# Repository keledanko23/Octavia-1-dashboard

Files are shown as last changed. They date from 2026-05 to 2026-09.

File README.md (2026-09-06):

# Octavia-1-Dashboard

A dashboard project.

## 📋 Project Overview

This is the Octavia-1 Dashboard - a comprehensive dashboard solution designed to use for pc simulators.
I have significantly expanded the scope of this project into a multi-phase hardware and software engineering build. I am converting a physical Skoda Octavia MK1 instrument cluster into a high-fidelity, real-time PC flight/racing simulator telemetry display.

## Current Progress (73 Hours Logged):

Hardware Reverse Engineering: Analyzed the internal trace lines, power rail limits, and motor pinouts of a replacement cluster following a previous hardware       failure (which was an excellent learning experience).
Interface Board Fabrication: Built a fully functional hardware interface on a 5x7cm barna perfboard, permanently soldering 3 driver ICs to safely handle logic     signal conversions between the microcontroller and the dashboard.
Complex Wire Harnessing: Engineered a point-to-point jumper wire harness to break out the connections. Applied hot-melt adhesive to insulate exposed solder        joints and provide mechanical strain relief.
Finished PCB design

## Remaining Scope:

Firmware Development: Writing custom python code using tkinter to simulate how it should work
Custom PCB Shield Design: Try to create a pcb for it.

## Diary

### 1st log (3.5 hours)
Analyzed the internal board layout of the replacement cluster. Traced the circuit lines to find the correct entry points for the stepper motors and indicators to avoid another hardware failure.
  ### Disassembly
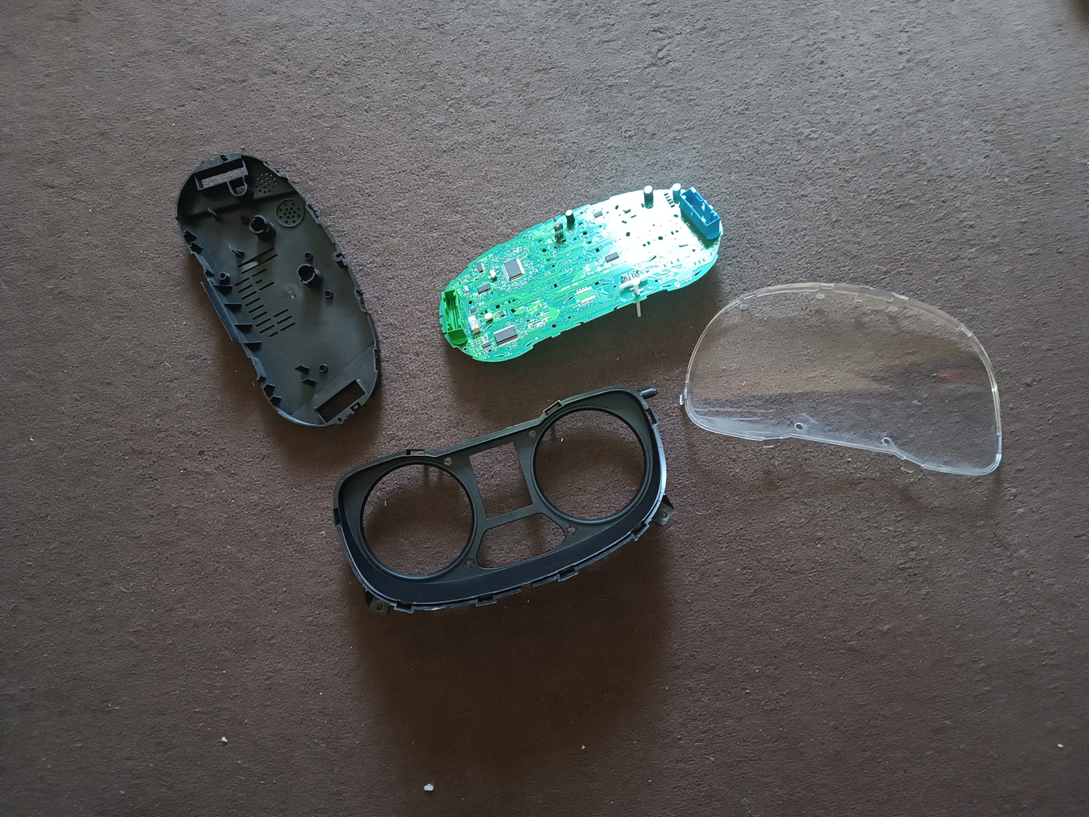
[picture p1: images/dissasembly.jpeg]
Disassembly
  

  ### LEDS
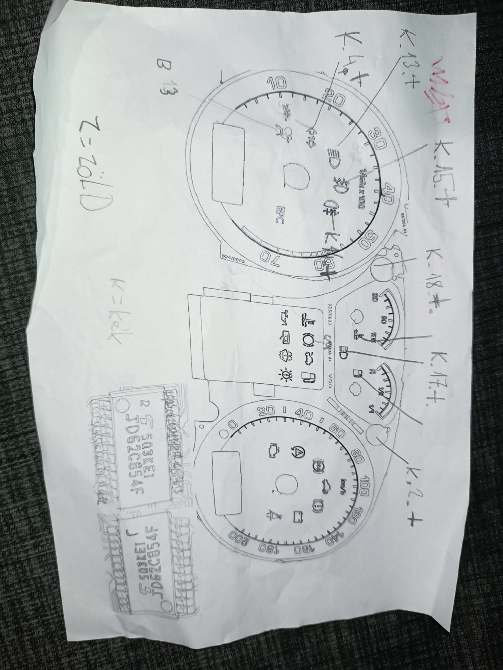
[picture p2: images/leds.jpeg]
LEDS
  

  ### Pinout
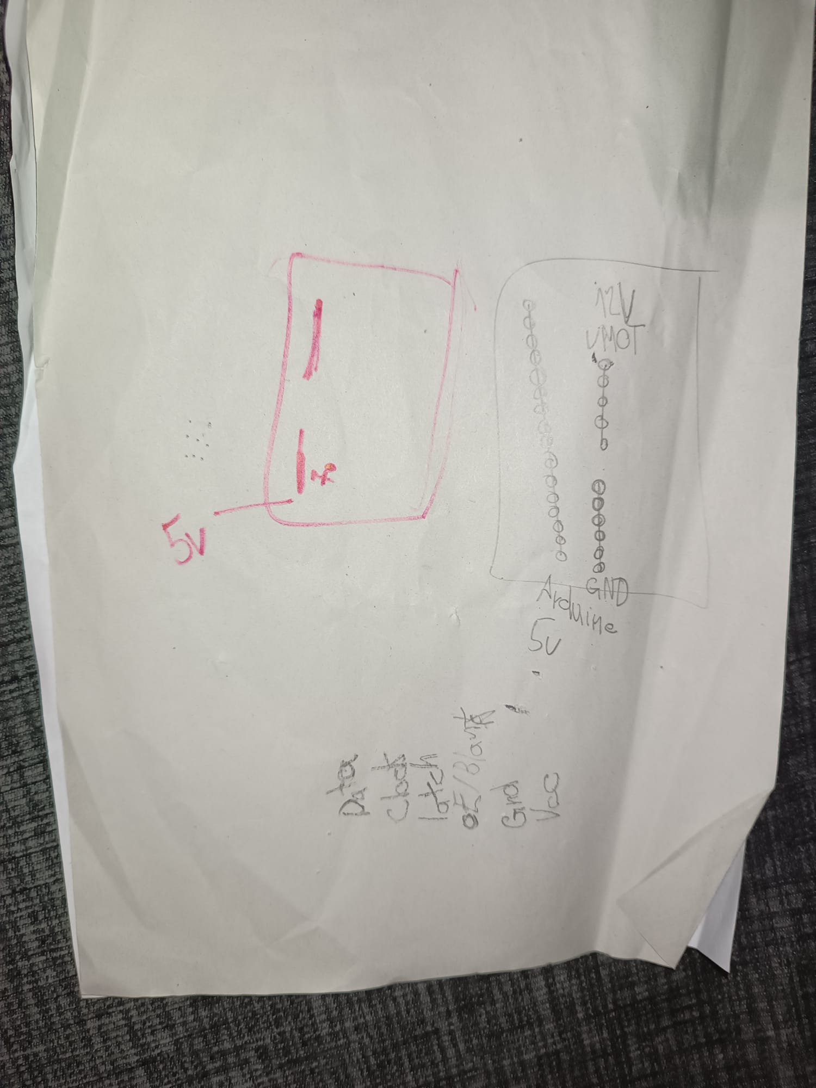
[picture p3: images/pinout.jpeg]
Pinout


## 2nd log (4 hours)
Mapped out the component placement on the 5x7cm barna perfboard. Positioned the three driver ICs and the male headers, then permanently soldered them onto the prototype board.

  ### ICs
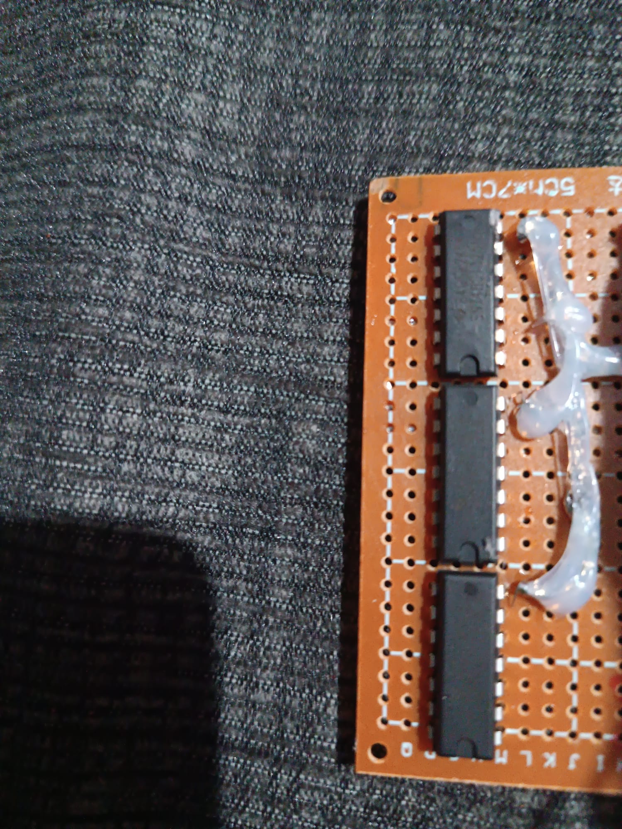
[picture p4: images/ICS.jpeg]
ICs
  

## 3rd log (4.5 hours)
Started building the complex point-to-point jumper wire harness. Stripped, routed, and soldered individual wires from the IC legs to the breakout headers to safely transfer signals.

  ### Wires
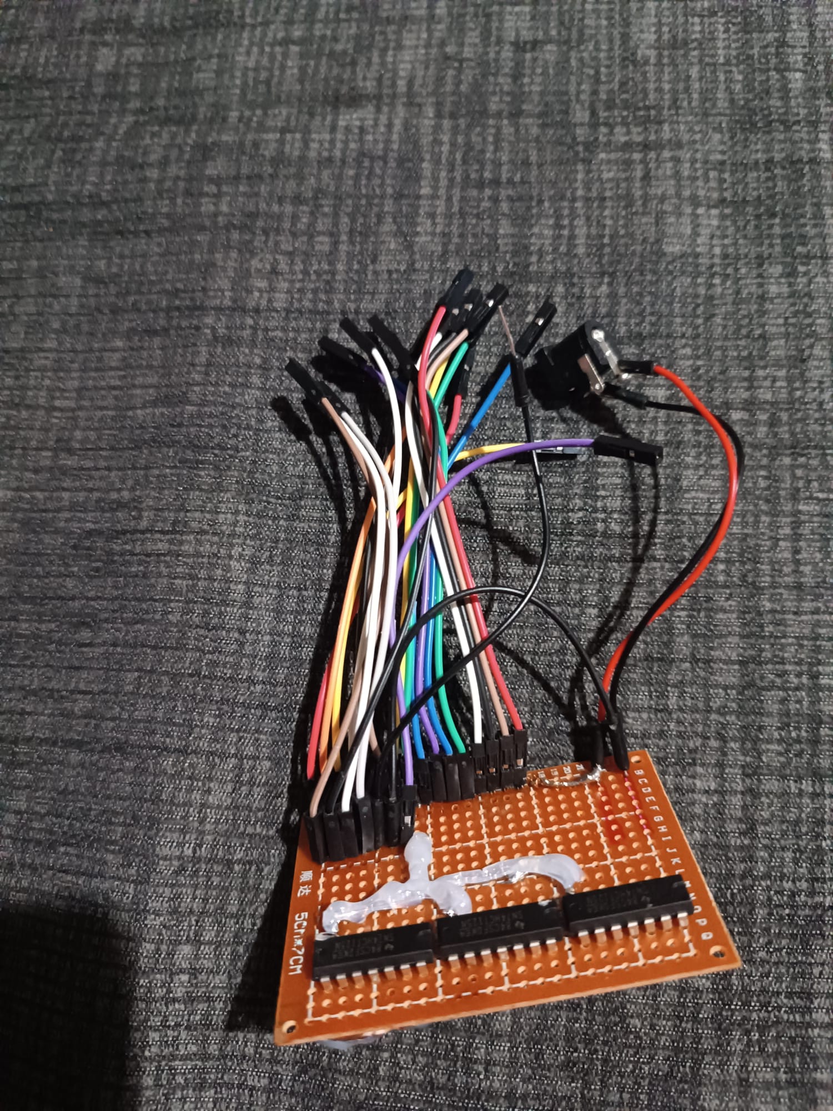
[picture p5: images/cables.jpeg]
Wires
  

## 4th log (4 hours)
Used a multimeter to test continuity on every single soldered connection. Checked for accidental solder bridges between the IC pins to prevent any short circuits before testing on live power.
 
  ### Checking
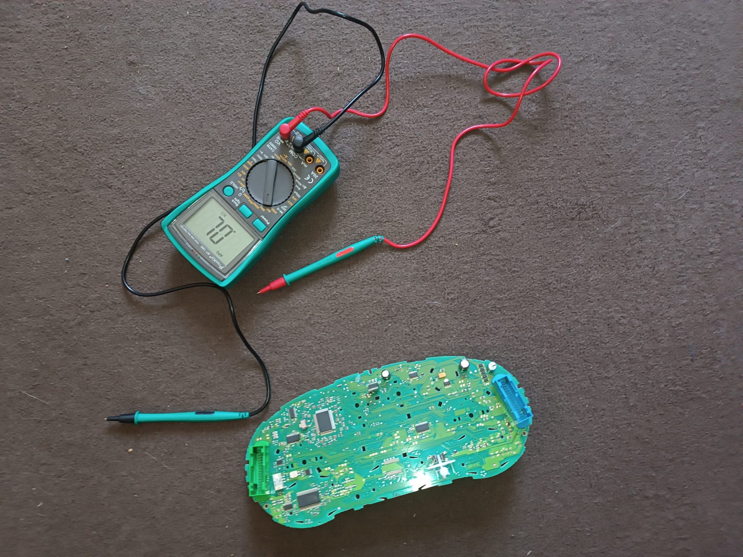
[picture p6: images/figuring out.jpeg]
Checking
  

## 5th log (4 hours)
Completed the hardware prototyping phase. Applied layers of hot-melt adhesive over the wire cluster to insulate the exposed solder joints and provide mechanical strain relief against loose connections.

  ### Coating
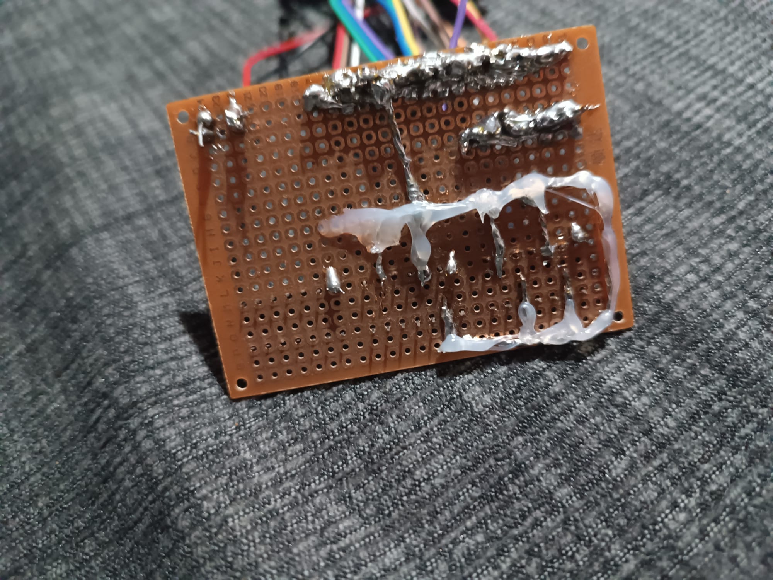
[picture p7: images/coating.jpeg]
Coating
  

## 6th log (5 hours)
Completed a simulation python code that shows how it will work.

  ### Python screenshot
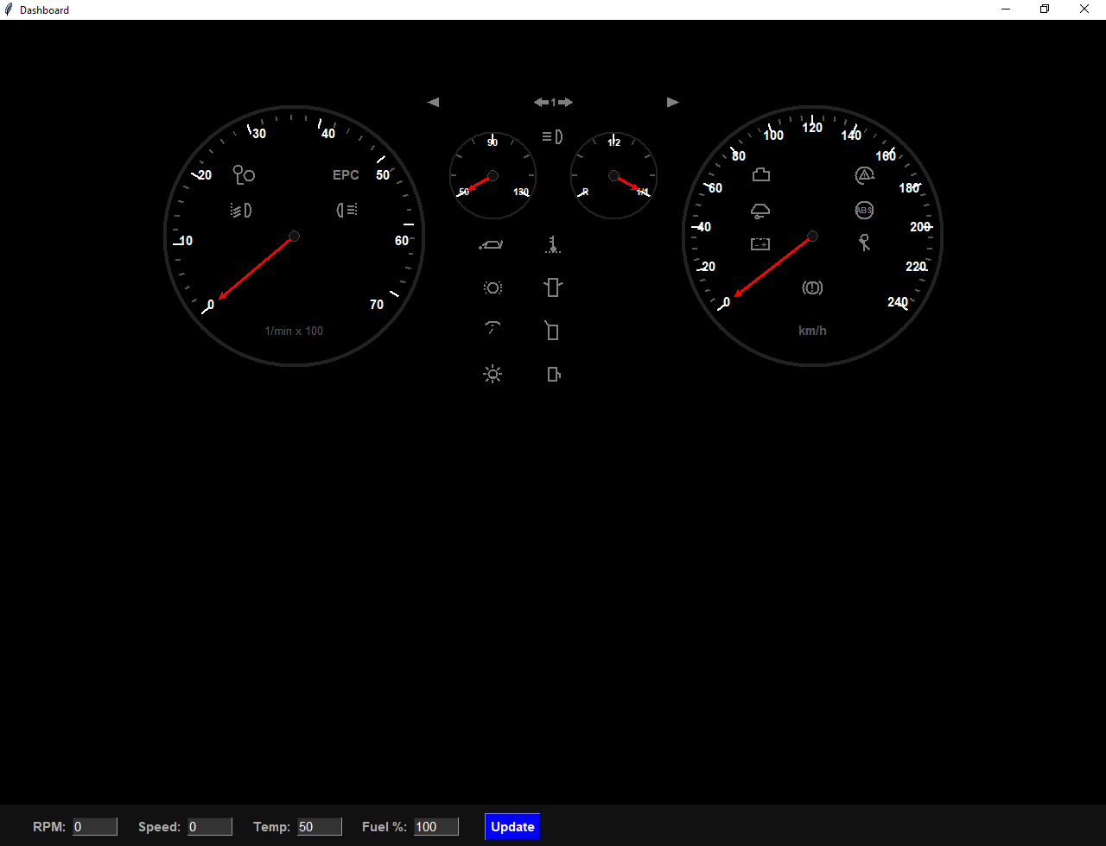
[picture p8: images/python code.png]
Python code
  

  ## DEMO LINK: https://youtu.be/50QhlQHXBYw

  ## PYTHON CODE [HERE](https://github.com/keledanko23/Octavia-1-dashboard/blob/main/Octavia%20mk1%20dashboard%20python%20code.py)
  
  ## 7th log(2.5 hours)
  Started mapping out the pcb so i can recreate it later, added 1more led to the prototype, tried to add 2more but they burned out
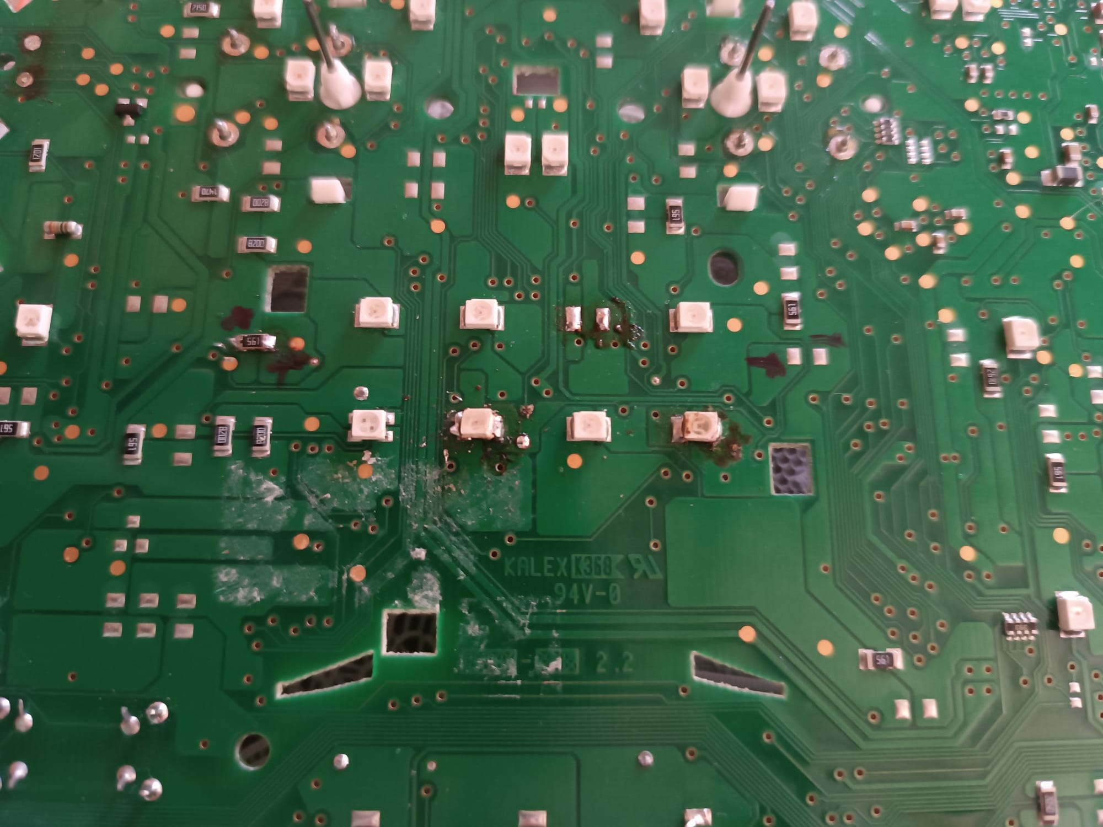
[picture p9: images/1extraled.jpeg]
LED
  
  
  ## 8th log(9.2 hours)
  Started building the pcb outlines and holes, unfortunatly lot of the holes arent on their places where they should be even if i mesure 10 times, at least the outline is finally the form i need and some of the holes ar on their places.
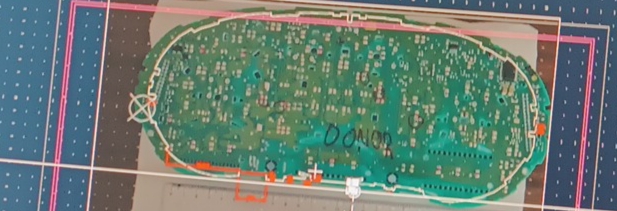
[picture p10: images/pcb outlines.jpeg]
Outlines
   
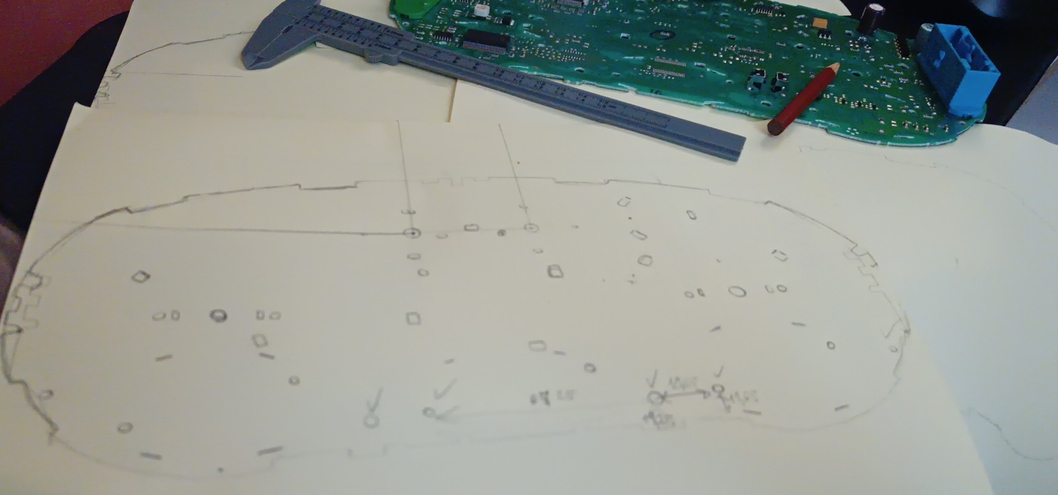
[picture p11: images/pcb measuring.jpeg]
Measuring
    

## 9th log(3.7 hours)
Finaly got a chance to use a scaner to scan the pcb, imported it into kicad ad fixed al the kholes location and the form of the pcb, the pcb form is now finished
  
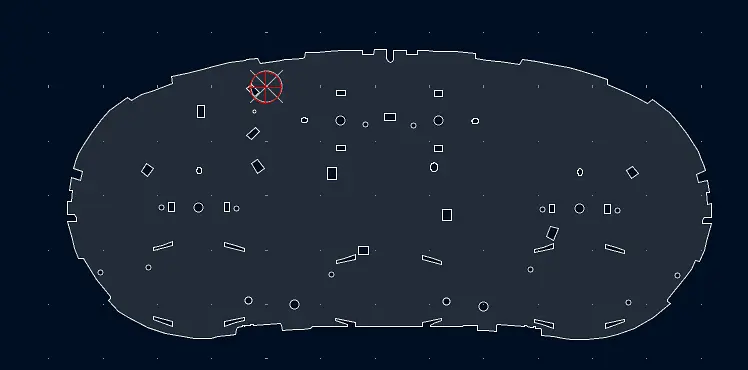
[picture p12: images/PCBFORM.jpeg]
PCB form
  

## 10th log(7 hours)
Drawed the schematic, it was really hard because I did not find some IC-s and had to draw them myself, at first it had 56errors but i managed to fix it

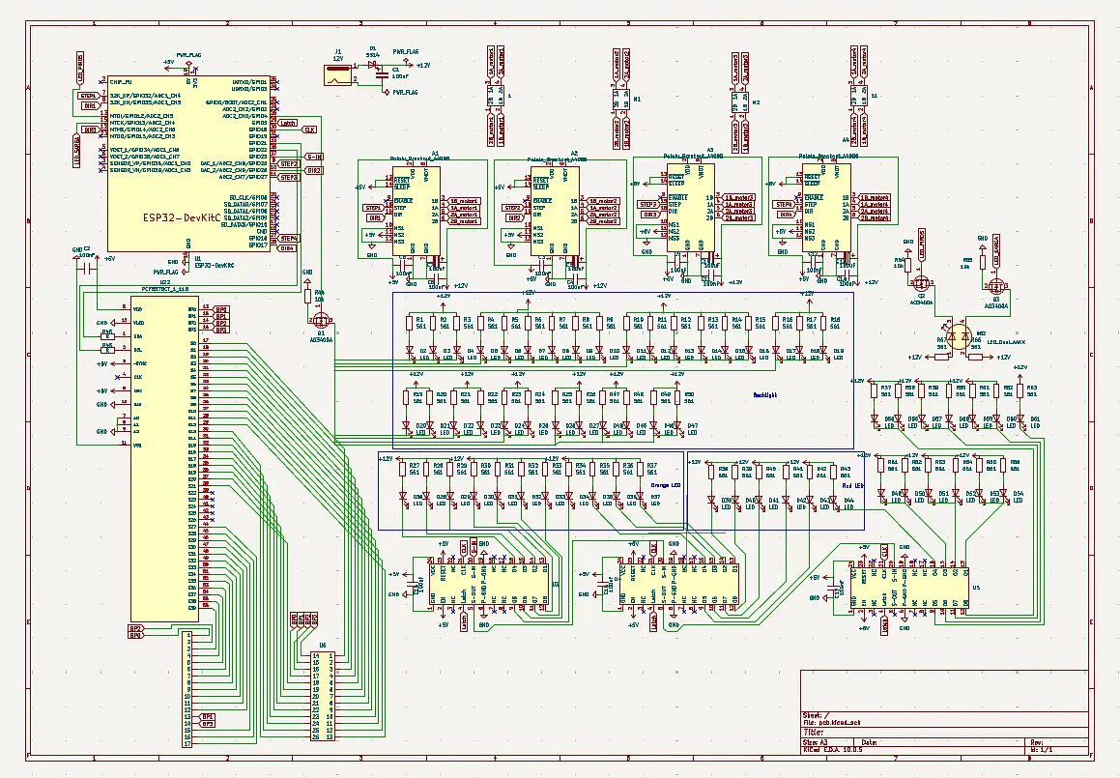
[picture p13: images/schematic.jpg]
Schematic


## 11th log(9 hours)
Added the components and conected most of the traces but I can´t make it cleaner, and i ran the DRC it said it has 250 errors and 110 alerts so i have a lot of work to do.

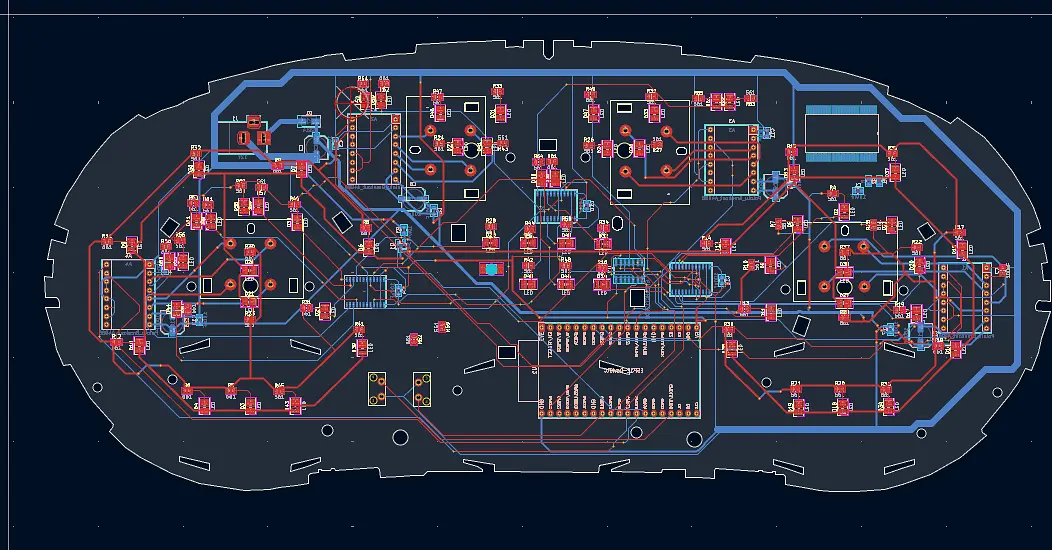
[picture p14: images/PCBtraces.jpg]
PCB traces


## 12th log(9.2 hours)
Fixed the layout, changed some expensive IC-s to cheaper ones, almost finished

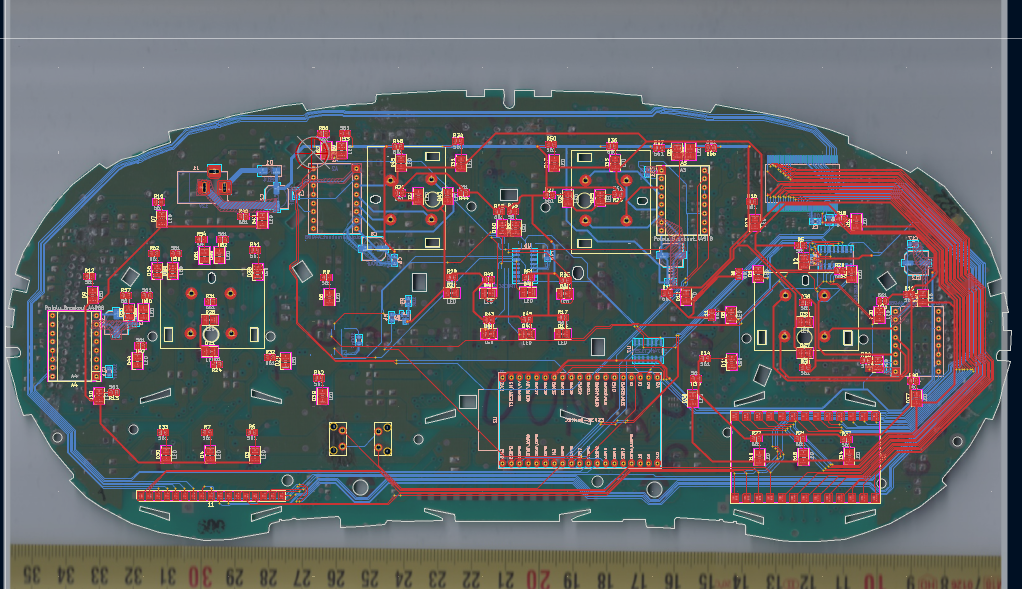
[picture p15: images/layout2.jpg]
Layout


## 13th log(5.8 hours)
Finally finished the pcb, it´s ready for order

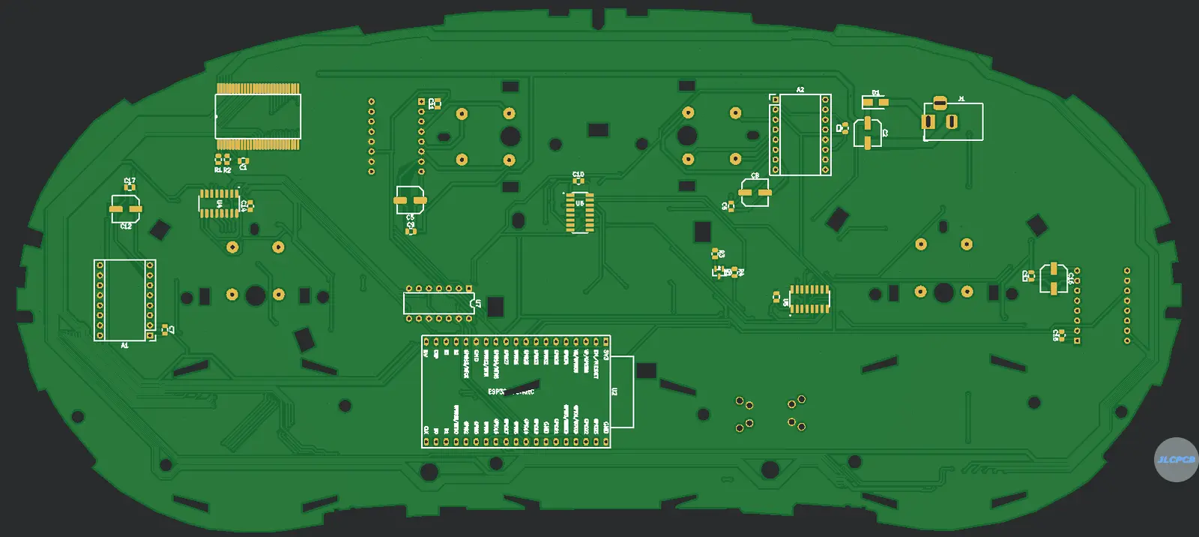
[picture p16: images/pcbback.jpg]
PCB back

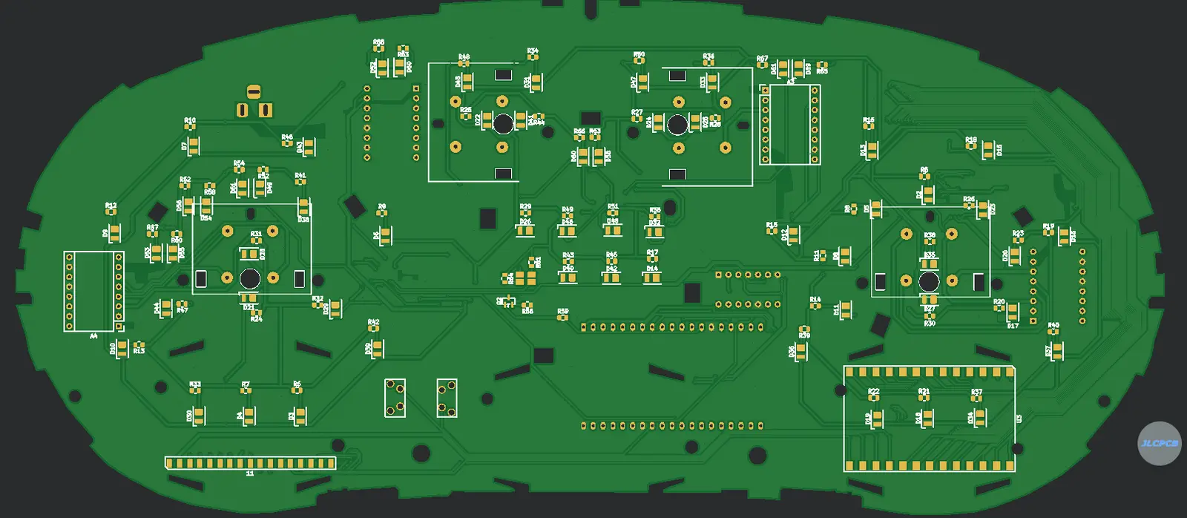
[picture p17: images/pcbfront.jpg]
PCB front


## PCB FILES [HERE](https://github.com/keledanko23/Octavia-1-dashboard/tree/main/PCB%20FILES)

## [BOM IN TABLE FOMRAT](https://docs.google.com/spreadsheets/d/1glcknnUEBRp5D3enFJscNNNqzlTzyaNK3k0CQGIx504/edit?usp=sharing)

**Last Updated:** August 29, 2026

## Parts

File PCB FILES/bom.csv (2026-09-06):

Designator | Footprint | Quantity | Value | LCSC Part #
11 | LCDPADS_LEFT1 | 1 | ~
21, 31, M1, M2 | Bez názvu | 4 | ~
A1, A2, A3, A4 | Pololu_Breakout-16_15.2x20.3mm | 4 | Pololu_Breakout_A4988
C1, C10, C11, C13, C14, C15, C17, C3, C4, C6, C7, C9 | 0805 | 12 | 100nF
C12, C16, C2, C5, C8 | C_Elec_6.3x7.7 | 5 | 100uF
D1 | D_DO-15_P10.16mm_Horizontal | 1 | SS14
D10, D11, D12, D13, D14, D15, D16, D17, D18, D19, D2, D20, D21, D22, D23, D24, D25, D26, D27, D28, D29, D3, D30, D31, D32, D33, D34, D35, D36, D37, D38, D39, D4, D40, D41, D42, D43, D44, D45, D46, D47, D48, D49, D5, D50, D51, D52, D53, D54, D55, D56, D58, D59, D6, D60, D61, D62, D63, D7, D8, D9 | LED_PLCC_2835_Handsoldering | 61 | LED
J1 | BarrelJack_Horizontal | 1 | 12V
Q1, Q2 | SOT-23_Handsoldering | 2 | AO3400A
R1, R2 | 0805 | 2 | 4,7k
R10, R11, R12, R13, R14, R15, R16, R17, R18, R19, R20, R21, R22, R23, R24, R25, R26, R27, R28, R29, R30, R31, R32, R33, R34, R35, R36, R37, R38, R39, R40, R41, R42, R43, R44, R45, R46, R47, R48, R49, R5, R50, R51, R52, R53, R54, R55, R57, R58, R6, R60, R62, R63, R64, R65, R66, R67, R68, R7, R8, R9 | 0805 | 61 | 561
R3, R56 | 0805 | 2 | 10k
R4, R59 | 0805 | 2 | 331
SW1, SW2 | Bez názvu | 2 | SW_Push
U1 | PCFCHIP | 1 | PCF8576CT_1_118 | PCF8576CT/1,118
U2 | ESP32-DevKitC | 1 | ESP32-DevKitC
U3 | LCDPADS_RIGHT1 | 1 | ~
U4, U5, U6 | SOIC127P600X175-16N | 3 | TPIC6C595DG4
U7 | DIP-14_W7.62mm | 1 | SN74HCT125DR

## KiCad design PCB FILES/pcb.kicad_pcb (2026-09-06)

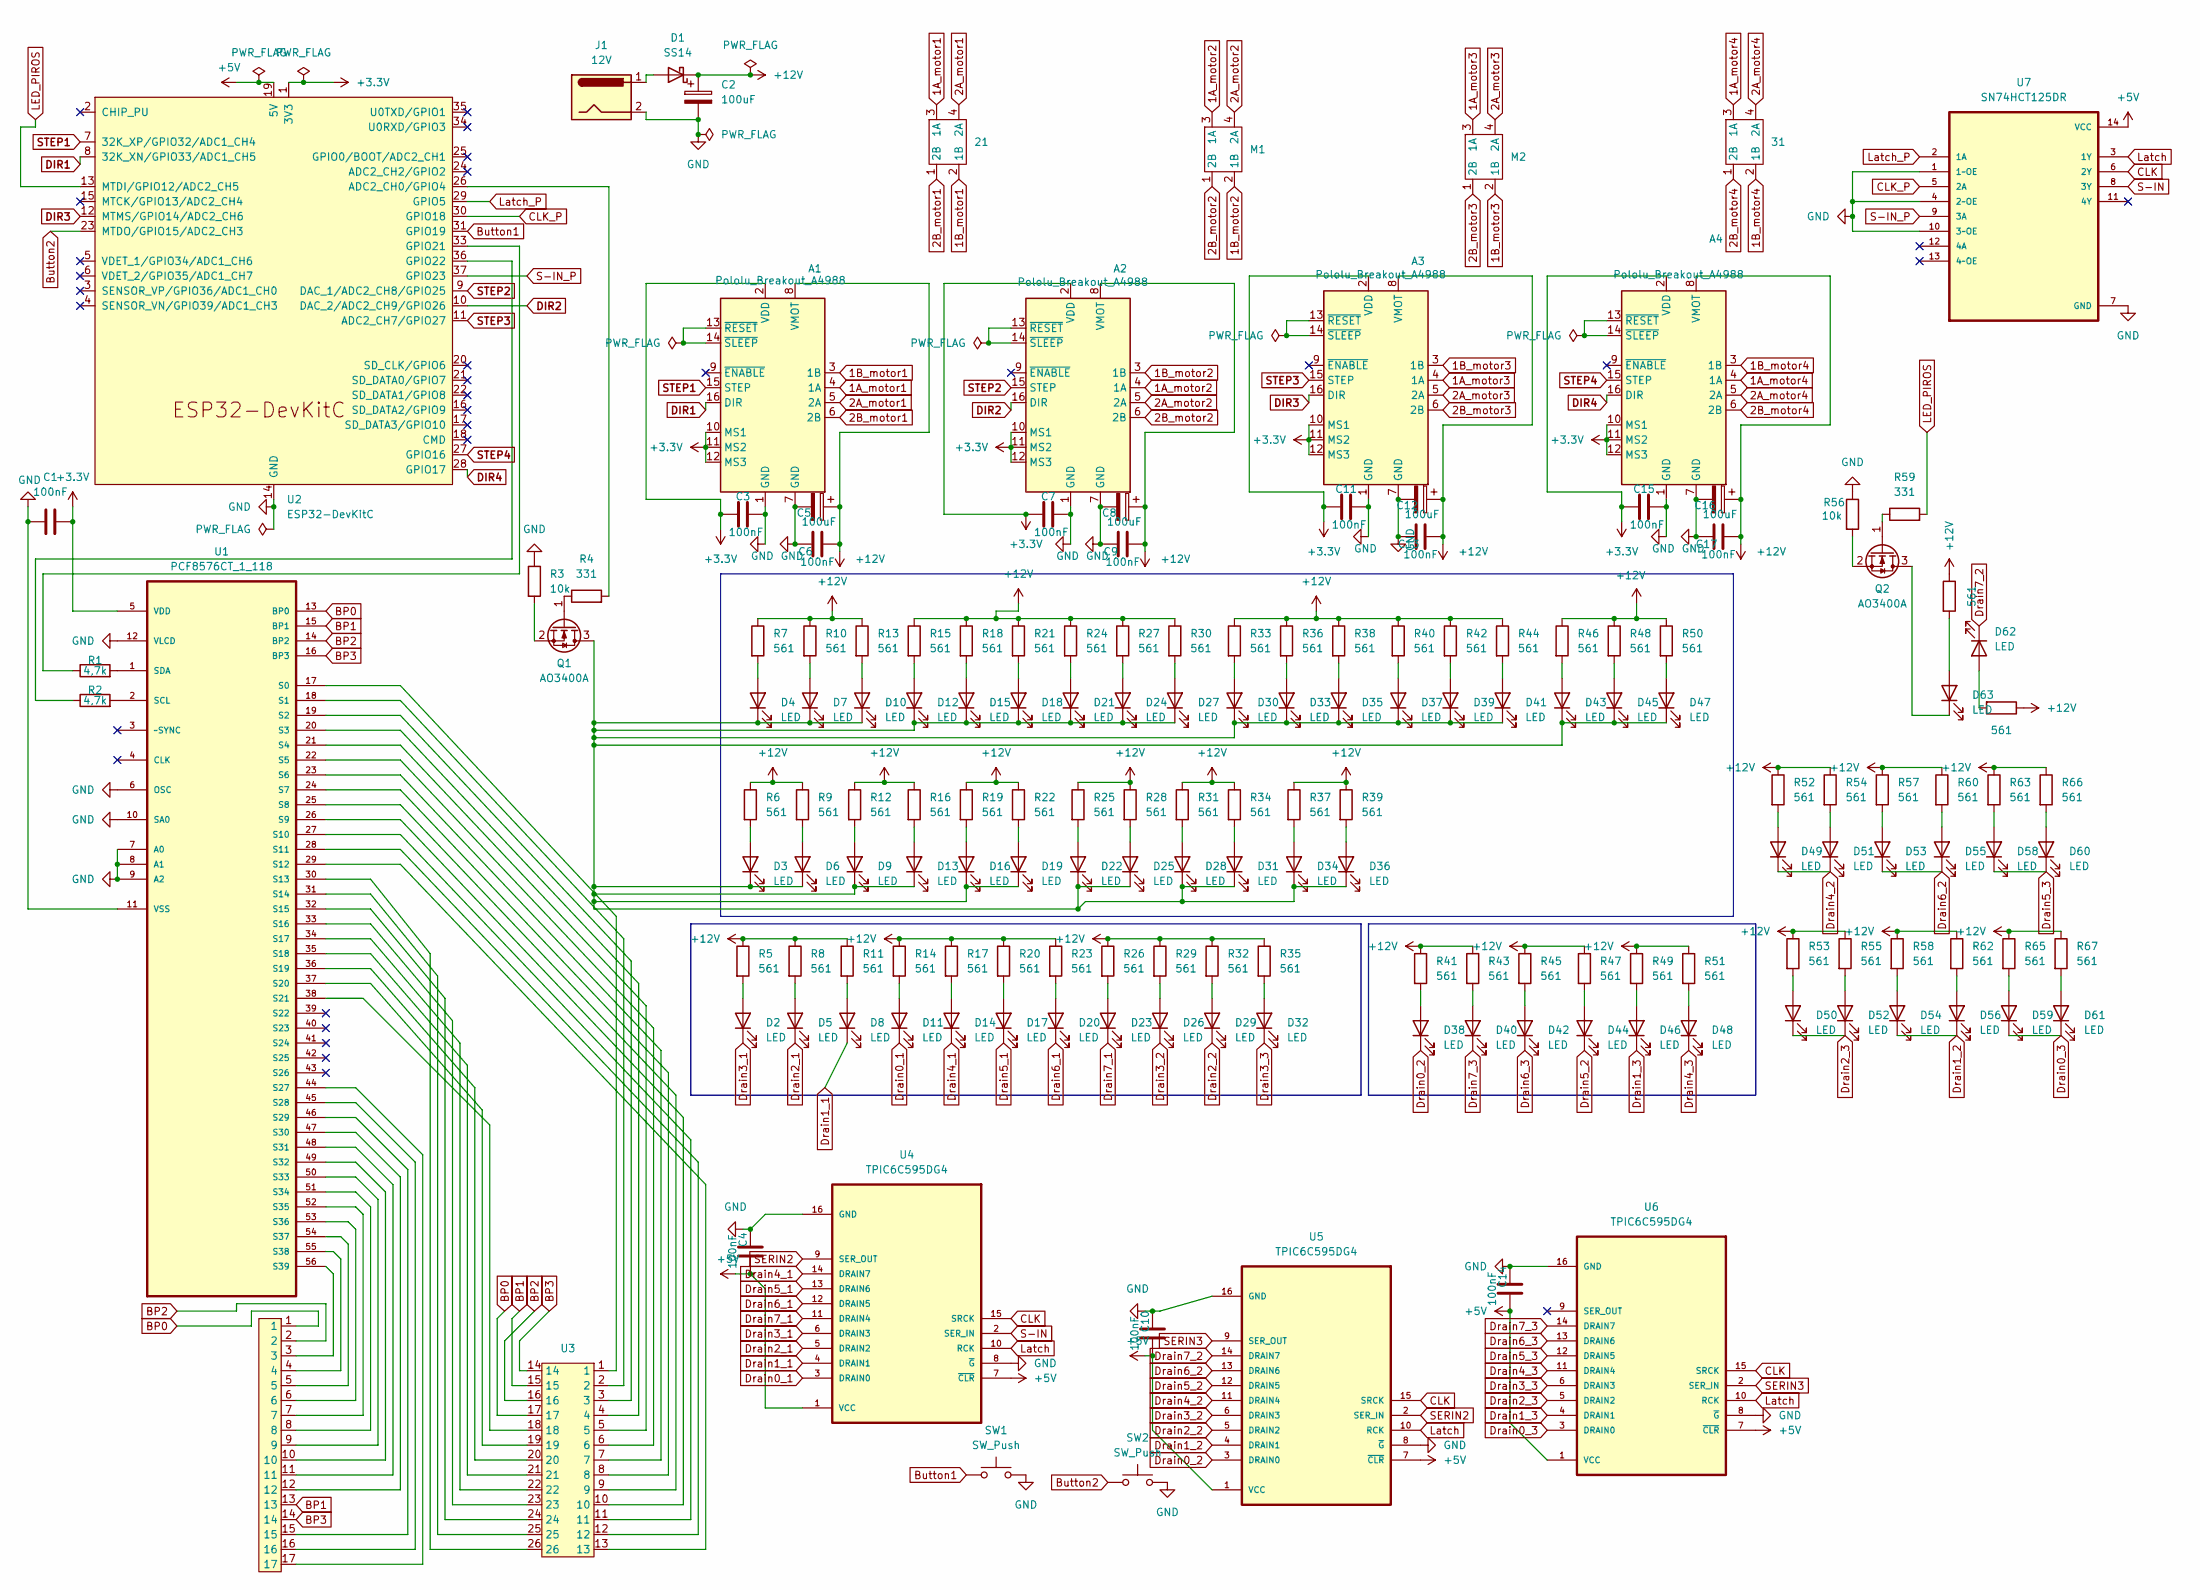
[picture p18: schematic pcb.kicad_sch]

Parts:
11: LCDPADS_LEFT1
21, 31: Bez názvu
A1, A2, A3, A4: Pololu_Breakout_A4988; Pololu_Breakout-16_15.2x20.3mm
C1, C3, C4, C6, C7, C9, C10, C11, C13, C14, C15, C17: 100nF; C_0805_2012Metric_Pad1.18x1.45mm_HandSolder
C2, C5, C8, C12, C16: 100uF; C_Elec_6.3x7.7
D1: SS14; D_DO-15_P10.16mm_Horizontal
D2, D3, D4, D5, D6, D7, D8, D9, D10, D11, D12, D13, D14, D15, D16, D17, D18, D19, D20, D21, D22, D23, D24, D25, D26, D27, D28, D29, D30, D31, D32, D33, D34, D35, D36, D37, D38, D39, D40, D41, D42, D43, D44, D45, D46, D47, D48, D49, D50, D51, D52, D53, D54, D55, D56, D58, D59, D60, D61, D62, D63: LED; LED_PLCC_2835_Handsoldering
J1: 12V; BarrelJack_Horizontal
M1, M2: Bez názvu
Q1, Q2: AO3400A; SOT-23_Handsoldering
R1, R2: 4,7k; R_0805_2012Metric_Pad1.20x1.40mm_HandSolder
R3, R56: 10k; R_0805_2012Metric_Pad1.20x1.40mm_HandSolder
R4, R59: 331; R_0805_2012Metric_Pad1.20x1.40mm_HandSolder
R5, R6, R7, R8, R9, R10, R11, R12, R13, R14, R15, R16, R17, R18, R19, R20, R21, R22, R23, R24, R25, R26, R27, R28, R29, R30, R31, R32, R33, R34, R35, R36, R37, R38, R39, R40, R41, R42, R43, R44, R45, R46, R47, R48, R49, R50, R51, R52, R53, R54, R55, R57, R58, R60, R62, R63, R64, R65, R66, R67, R68: 561; R_0805_2012Metric_Pad1.20x1.40mm_HandSolder
SW1, SW2: SW_Push; Bez názvu
U1: PCF8576CT_1_118; PCFCHIP; MPN PCF8576CT/1,118
U2: ESP32-DevKitC
U3: LCDPADS_RIGHT1
U4, U5, U6: TPIC6C595DG4; SOIC127P600X175-16N
U7: SN74HCT125DR; DIP-14_W7.62mm

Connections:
1A_motor1: 21.3 (1A), A1.4 (1A)
1A_motor2: A2.4 (1A), M1.3 (1A)
1A_motor3: A3.4 (1A), M2.3 (1A)
1A_motor4: 31.3 (1A), A4.4 (1A)
1B_motor1: 21.2 (1B), A1.3 (1B)
1B_motor2: A2.3 (1B), M1.2 (1B)
1B_motor3: A3.3 (1B), M2.2 (1B)
1B_motor4: 31.2 (1B), A4.3 (1B)
2A_motor1: 21.4 (2A), A1.5 (2A)
2A_motor2: A2.5 (2A), M1.4 (2A)
2A_motor3: A3.5 (2A), M2.4 (2A)
2A_motor4: 31.4 (2A), A4.5 (2A)
2B_motor1: 21.1 (2B), A1.6 (2B)
2B_motor2: A2.6 (2B), M1.1 (2B)
2B_motor3: A3.6 (2B), M2.1 (2B)
2B_motor4: 31.1 (2B), A4.6 (2B)
+3.3V: A1.2 (VDD), A1.10 (MS1), A1.11 (MS2), A1.12 (MS3), A2.2 (VDD), A2.10 (MS1), A2.11 (MS2), A2.12 (MS3), A3.2 (VDD), A3.10 (MS1), A3.11 (MS2), A3.12 (MS3), A4.2 (VDD), A4.10 (MS1), A4.11 (MS2), A4.12 (MS3), C1.2, C3.1, C7.1, C11.1, C15.1, U1.5 (VDD), U2.1 (3V3)
+5V: C4.2, C10.2, C14.2, U2.19 (5V), U4.1 (VCC), U4.7 (~CLR), U5.1 (VCC), U5.7 (~CLR), U6.1 (VCC), U6.7 (~CLR), U7.14 (VCC)
+12V: A1.8 (VMOT), A2.8 (VMOT), A3.8 (VMOT), A4.8 (VMOT), C2.1, C5.1, C6.2, C8.1, C9.2, C12.1, C13.2, C16.1, C17.2, D1.1 (K), R5.1, R6.1, R7.1, R8.1, R9.1, R10.1, R11.1, R12.1, R13.1, R14.1, R15.1, R16.1, R17.1, R18.1, R19.1, R20.1, R21.1, R22.1, R23.1, R24.1, R25.1, R26.1, R27.1, R28.1, R29.1, R30.1, R31.1, R32.1, R33.1, R34.1, R35.1, R36.1, R37.1, R38.1, R39.1, R40.1, R41.1, R42.1, R43.1, R44.1, R45.1, R46.1, R47.1, R48.1, R49.1, R50.1, R51.1, R52.1, R53.1, R54.1, R55.1, R57.1, R58.1, R60.1, R62.1, R63.1, R64.1, R65.1, R66.1, R67.1, R68.1
BP0: 11.1, U1.13 (BP0), U3.17
BP1: 11.13, U1.15 (BP1), U3.15
BP2: 11.2, U1.14 (BP2), U3.16
BP3: 11.14, U1.16 (BP3), U3.14
Button1: SW1.1, U2.31 (GPIO19)
Button2: SW2.1, U2.23 (MTDO/GPIO15/ADC2_CH3)
CLK: U4.15 (SRCK), U5.15 (SRCK), U6.15 (SRCK), U7.6 (2Y)
CLK_P: U2.30 (GPIO18), U7.5 (2A)
DIR1: A1.16 (DIR), U2.8 (32K_XN/GPIO33/ADC1_CH5)
DIR2: A2.16 (DIR), U2.10 (DAC_2/ADC2_CH9/GPIO26)
DIR3: A3.16 (DIR), U2.12 (MTMS/GPIO14/ADC2_CH6)
DIR4: A4.16 (DIR), U2.28 (GPIO17)
Drain0_1: D11.1 (K), U4.3 (DRAIN0)
Drain0_2: D38.1 (K), U5.3 (DRAIN0)
Drain0_3: D59.1 (K), D61.1 (K), U6.3 (DRAIN0)
Drain1_1: D8.1 (K), U4.4 (DRAIN1)
Drain1_2: D54.1 (K), D56.1 (K), U5.4 (DRAIN1)
Drain1_3: D46.1 (K), U6.4 (DRAIN1)
Drain2_1: D5.1 (K), U4.5 (DRAIN2)
Drain2_2: D29.1 (K), U5.5 (DRAIN2)
Drain2_3: D50.1 (K), D52.1 (K), U6.5 (DRAIN2)
Drain3_1: D2.1 (K), U4.6 (DRAIN3)
Drain3_2: D26.1 (K), U5.6 (DRAIN3)
Drain3_3: D32.1 (K), U6.6 (DRAIN3)
Drain4_1: D14.1 (K), U4.14 (DRAIN7)
Drain4_2: D49.1 (K), D51.1 (K), U5.11 (DRAIN4)
Drain4_3: D48.1 (K), U6.11 (DRAIN4)
Drain5_1: D17.1 (K), U4.13 (DRAIN6)
Drain5_2: D44.1 (K), U5.12 (DRAIN5)
Drain5_3: D58.1 (K), D60.1 (K), U6.12 (DRAIN5)
Drain6_1: D20.1 (K), U4.12 (DRAIN5)
Drain6_2: D53.1 (K), D55.1 (K), U5.13 (DRAIN6)
Drain6_3: D42.1 (K), U6.13 (DRAIN6)
Drain7_1: D23.1 (K), U4.11 (DRAIN4)
Drain7_2: D62.1 (K), U5.14 (DRAIN7)
Drain7_3: D40.1 (K), U6.14 (DRAIN7)
GND: A1.1 (GND), A1.7 (GND), A2.1 (GND), A2.7 (GND), A3.1 (GND), A3.7 (GND), A4.1 (GND), A4.7 (GND), C1.1, C2.2, C3.2, C4.1, C5.2, C6.1, C7.2, C8.2, C9.1, C10.1, C11.2, C12.2, C13.1, C14.1, C15.2, C16.2, C17.1, J1.2, R3.1, R56.1, SW1.2, SW2.2, U1.6 (OSC), U1.7 (A0), U1.8 (A1), U1.9 (A2), U1.10 (SA0), U1.11 (VSS), U1.12 (VLCD), U2.14 (GND), U2.32 (GND), U2.38 (GND), U4.8 (~G), U4.16 (GND), U5.8 (~G), U5.16 (GND), U6.8 (~G), U6.16 (GND), U7.1 (1~OE), U7.4 (2~OE), U7.7 (GND), U7.10 (3~OE)
LED_PIROS: R59.2, U2.13 (MTDI/GPIO12/ADC2_CH5)
Latch: U4.10 (RCK), U5.10 (RCK), U6.10 (RCK), U7.3 (1Y)
Latch_P: U2.29 (GPIO5), U7.2 (1A)
unnamed: A1.13 (~RESET), A1.14 (~SLEEP)
unnamed: A2.13 (~RESET), A2.14 (~SLEEP)
unnamed: A3.13 (~RESET), A3.14 (~SLEEP)
unnamed: A4.13 (~RESET), A4.14 (~SLEEP)
unnamed: D1.2 (A), J1.1
unnamed: D2.2 (A), R5.2
unnamed: D3.2 (A), R6.2
unnamed: D4.2 (A), R7.2
unnamed: D5.2 (A), R8.2
unnamed: D6.2 (A), R9.2
unnamed: D7.2 (A), R10.2
unnamed: D8.2 (A), R11.2
unnamed: D9.2 (A), R12.2
unnamed: D10.2 (A), R13.2
unnamed: D3.1 (K), D4.1 (K), D6.1 (K), D7.1 (K), D9.1 (K), D10.1 (K), D12.1 (K), D13.1 (K), D15.1 (K), D16.1 (K), D18.1 (K), D19.1 (K), D21.1 (K), D22.1 (K), D24.1 (K), D25.1 (K), D27.1 (K), D28.1 (K), D30.1 (K), D31.1 (K), D33.1 (K), D34.1 (K), D35.1 (K), D36.1 (K), D37.1 (K), D39.1 (K), D41.1 (K), D43.1 (K), D45.1 (K), D47.1 (K), Q1.3 (D)
unnamed: D11.2 (A), R14.2
unnamed: D12.2 (A), R15.2
unnamed: D13.2 (A), R16.2
unnamed: D14.2 (A), R17.2
unnamed: D15.2 (A), R18.2
unnamed: D16.2 (A), R19.2
unnamed: D17.2 (A), R20.2
unnamed: D18.2 (A), R21.2
unnamed: D19.2 (A), R22.2
unnamed: D20.2 (A), R23.2
unnamed: D21.2 (A), R24.2
unnamed: D22.2 (A), R25.2
unnamed: D23.2 (A), R26.2
unnamed: D24.2 (A), R27.2
unnamed: D25.2 (A), R28.2
unnamed: D26.2 (A), R29.2
unnamed: D27.2 (A), R30.2
unnamed: D28.2 (A), R31.2
unnamed: D29.2 (A), R32.2
unnamed: D30.2 (A), R33.2
unnamed: D31.2 (A), R34.2
unnamed: D32.2 (A), R35.2
unnamed: D33.2 (A), R36.2
unnamed: D34.2 (A), R37.2
unnamed: D35.2 (A), R38.2
unnamed: D36.2 (A), R39.2
unnamed: D37.2 (A), R40.2
unnamed: D38.2 (A), R41.2
unnamed: D39.2 (A), R42.2
unnamed: D40.2 (A), R43.2
unnamed: D41.2 (A), R44.2
unnamed: D42.2 (A), R45.2
unnamed: D43.2 (A), R46.2
unnamed: D44.2 (A), R47.2
unnamed: D45.2 (A), R48.2
unnamed: D46.2 (A), R49.2
unnamed: D47.2 (A), R50.2
unnamed: D48.2 (A), R51.2
unnamed: D49.2 (A), R52.2
unnamed: D50.2 (A), R53.2
unnamed: D51.2 (A), R54.2
unnamed: D52.2 (A), R55.2
unnamed: D53.2 (A), R57.2
unnamed: D54.2 (A), R58.2
unnamed: D55.2 (A), R60.2
unnamed: D56.2 (A), R62.2
unnamed: D58.2 (A), R63.2
unnamed: D59.2 (A), R65.2
unnamed: D60.2 (A), R66.2
unnamed: D61.2 (A), R67.2
unnamed: D62.2 (A), R64.2
unnamed: D63.2 (A), R68.2
unnamed: D63.1 (K), Q2.3 (D)
unnamed: Q1.1 (G), R4.1
unnamed: Q1.2 (S), R3.2
unnamed: Q2.1 (G), R59.1
unnamed: Q2.2 (S), R56.2
unnamed: U1.17 (S0), U3.1
unnamed: U1.18 (S1), U3.2
unnamed: U1.19 (S2), U3.3
unnamed: U1.20 (S3), U3.4
unnamed: U1.21 (S4), U3.5
unnamed: U1.22 (S5), U3.6
unnamed: U1.23 (S6), U3.7
unnamed: U1.24 (S7), U3.8
unnamed: U1.25 (S8), U3.9
unnamed: U1.26 (S9), U3.10
unnamed: U1.27 (S10), U3.11
unnamed: U1.28 (S11), U3.12
unnamed: U1.29 (S12), U3.13
unnamed: U1.30 (S13), U3.26
unnamed: U1.31 (S14), U3.25
unnamed: U1.32 (S15), U3.24
unnamed: U1.33 (S16), U3.23
unnamed: U1.34 (S17), U3.22
unnamed: U1.35 (S18), U3.21
unnamed: U1.36 (S19), U3.20
unnamed: U1.37 (S20), U3.19
unnamed: U1.38 (S21), U3.18
unnamed: 11.17, U1.44 (S27)
unnamed: 11.16, U1.45 (S28)
unnamed: 11.15, U1.46 (S29)
unnamed: 11.12, U1.47 (S30)
unnamed: 11.11, U1.48 (S31)
unnamed: 11.10, U1.49 (S32)
unnamed: 11.9, U1.50 (S33)
unnamed: 11.8, U1.51 (S34)
unnamed: 11.7, U1.52 (S35)
unnamed: 11.6, U1.53 (S36)
unnamed: 11.5, U1.54 (S37)
unnamed: 11.4, U1.55 (S38)
unnamed: 11.3, U1.56 (S39)
unnamed: R2.2, U1.2 (SCL)
unnamed: R1.2, U1.1 (SDA)
unnamed: R4.2, U2.26 (ADC2_CH0/GPIO4)
unnamed: R1.1, U2.33 (GPIO21)
unnamed: R2.1, U2.36 (GPIO22)
S-IN: U4.2 (SER_IN), U7.8 (3Y)
S-IN_P: U2.37 (GPIO23), U7.9 (3A)
SERIN2: U4.9 (SER_OUT), U5.2 (SER_IN)
SERIN3: U5.9 (SER_OUT), U6.2 (SER_IN)
STEP1: A1.15 (STEP), U2.7 (32K_XP/GPIO32/ADC1_CH4)
STEP2: A2.15 (STEP), U2.9 (DAC_1/ADC2_CH8/GPIO25)
STEP3: A3.15 (STEP), U2.11 (ADC2_CH7/GPIO27)
STEP4: A4.15 (STEP), U2.27 (GPIO16)

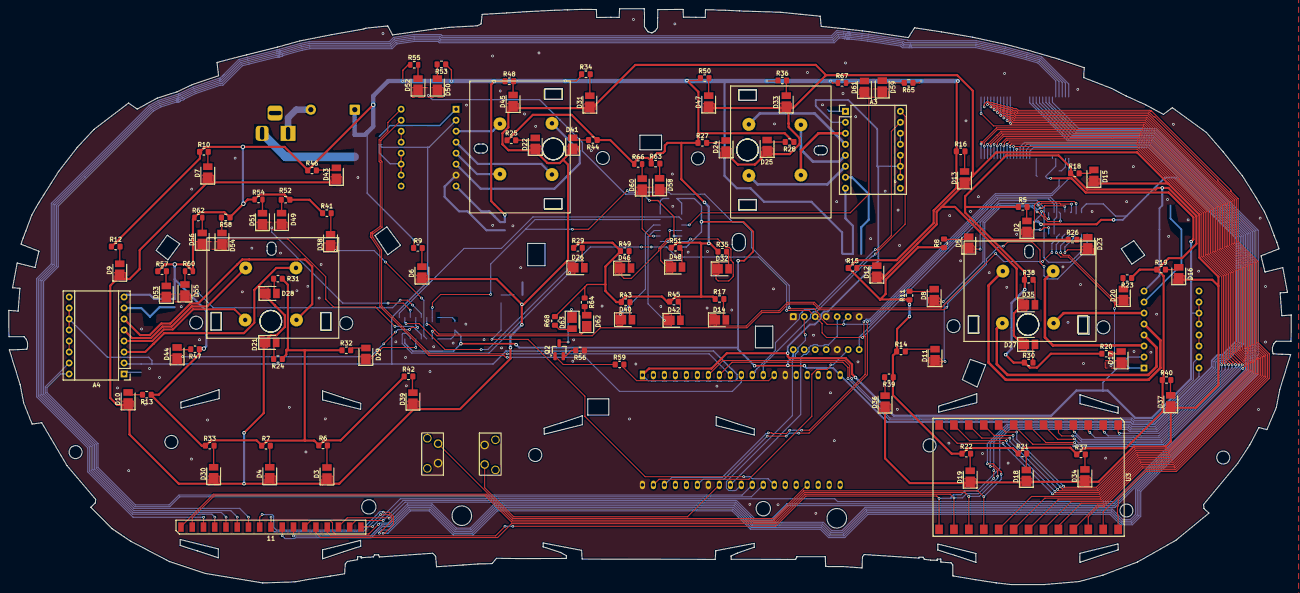
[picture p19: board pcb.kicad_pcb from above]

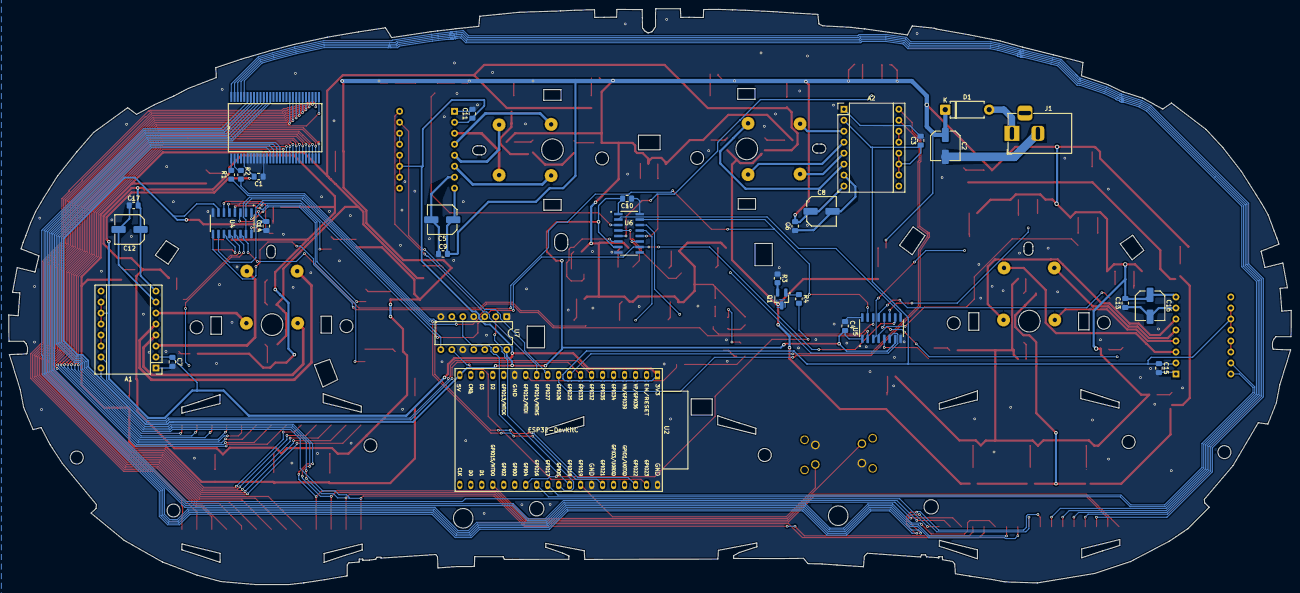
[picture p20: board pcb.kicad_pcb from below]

Board: 2 copper layers, 296.5 x 133.1 mm, 167 parts (32 on the bottom side), 179 nets.

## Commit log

2026-08-29 Update README with Python code and PCB files links
    Added links to Python code and PCB files in the README.
2026-08-29 Update README with progress and new sections
    Updated current progress hours logged and added new sections for finished PCB design and BOM in table format.
2026-10-30 Update README with latest log and date
    Added a log entry about soldering issues and updated the last updated date.
